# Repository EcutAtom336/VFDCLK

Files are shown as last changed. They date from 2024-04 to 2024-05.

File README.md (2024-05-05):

 # VFD 时钟 
 该项目是一个基于 ESP32 C3 微控制器的 VFD 时钟，可通过 Android 端软件进行配置
 ## 快速链接
 - [Github](https://github.com/EcutAtom336/VFDCLK/tree/master) 

 - [立创开源硬件平台](https://oshwhub.com/dter/vdf-clk)
 ## 特性
 - 使用 ESP32 C3 微控制器
 - 可通过 Android 端软件进行配置
 - 使用 VFD 显示屏，最高亮度 1000cd/m^2^
 - 内置一个蜂鸣器，可发出提示音
 - 内置光敏电阻，可实现自动亮度
 - 双 Type-C 设计，包含一个侧面 16Pin Type-C （下载和供电）和背面 6Pin Type-C （仅供电）
 - 右上螺丝可触摸设计，可进行简单交互

 ## 开始
 ### 所需工具
 - 镊子
 - 电烙铁
 - 热风枪 或 加热台
 - 万用表
 - 支持 USB 2.0 的 Type-C 数据线
 - 支持 BLE 的 Android 手机

 ### 调试建议
  1. 最后焊接 VFD 屏幕，以防加热损坏 VFD 屏幕。
  2. 烧录前先测试电源是否短路，以免损坏电脑 USB 接口。

 ### 烧录
 烧录时，请使用侧面 Type-C 接口。

 使用附件提供的 .bin 文件进行烧录，烧录方法如下。
 
 1. IDE 烧录
 [IDE 烧录方法](https://docs.espressif.com/projects/esp-techpedia/zh_CN/latest/esp-friends/get-started/try-firmware/try-firmware-platform.html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)
 2. Flash Download Tool 烧录
 [Flash Download Tool 烧录](https://docs.espressif.com/projects/esp-techpedia/zh_CN/latest/esp-friends/get-started/try-firmware/try-firmware-platform.html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)

 对于非开发人员，建议使用 Flash Download Tool 烧录。

 ## 使用方法
 1. 初次上电，长按右上螺丝 3s 进入配置模式，此时 VFD 时钟显示一次性设备码。
 2. 安装附件提供的 Android 软件进行配置。
 3. 当时间可能不准确时，时间分隔符会闪烁。

 ## 注意事项
 - 3D 外壳有两个，分为有脚垫和无脚垫（文件名分别为 shell_foot_pad.STL 和 shell_not_foor_pad.STL）。无脚垫的已验证。有脚垫的仅在无脚垫的基础上加上脚垫，未验证。
 - 面板打印选 1.5 mm 厚，只切割不打印。备注写“两款数量一样”。
 - 由于立创开源硬件平台审核机制，附件所提供的 apk 和 bin 可能不是最新，可前往 Github 查看是否有更新。
 - 为保证 ESP32 C3 天线校准成功以及系统稳定，请使用电压为 5V 且电流不低于 800mA 的电源进行供电。

 ## 安全提示
 - 尽管具有防回流设计，但也不要同时使用两个 Type-C 接口进行供电，以免发生意外。
 - 由于技术原因，配置时所输入的一次性设备码并不是蓝牙的配对码，因此时钟与 Android 手机并没有建立绑定关系，所以配置信息全部以明文发送。

 ## 未来可能更新的功能（画饼）
 - BLE OTA
 - 闹钟功能
 - 配置信息加密
 - 校园网认证

 ## 许可证
 本项目使用 GPL 3.0 许可证。

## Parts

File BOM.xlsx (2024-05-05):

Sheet: BOM
No. | Quantity | Designator | Footprint | Value | Device
1 | 1 | BUZZER1 | BUZ-SMD_L5.0-W5.5-P4.60 | 4kHz | MLT-5020
2 | 3 | C1,C7,C8 | C0603 | 10uF | CL10A106KP8NNNC
3 | 8 | C2,C3,C4,C9,C11,C14,C18,C22 | C0603 | 100nF | CAP_0603
4 | 3 | C5,C15,C17 | C0603 | 10nF | 0603B103K500NT
5 | 2 | C6,C19 | C0603 | 1uF | CAP_0603
6 | 4 | C10,C12,C13,C23 | C0805 | 22uF | CAP_0805
7 | 1 | C16 | C0603 | 22nF | CL10B223KB8NNNC
8 | 1 | C20 | C0603 | 22pF | CAP_0603
9 | 1 | C21 | C0603 | 20pF | CAP_0603
10 | 2 | D1,D4 | SOD-323_L1.8-W1.3-LS2.5-RD |  | 1N5819WS_C191023
11 | 2 | D2,D3 | SMA_L4.3-W2.6-LS5.0-RD |  | SS14_C2837270
12 | 1 | H1 | HDR-TH_4P-P2.54-V-M |  | HDR-M_2.54_1x4P
13 | 2 | L1,L2 | IND-SMD_L4.4-W4.2 | 6.8uH | FXL0420-6R8-M
14 | 1 | Q1 | SOT-23-3_L2.9-W1.3-P1.90-LS2.4-BR |  | SS8050_C2150
15 | 2 | R1,R2 | R0603 | 10R | Res_0603
16 | 1 | R3 | R0603 | 39K | Res_0603
17 | 4 | R4,R5,R6,R18 | R0603 | 10K | Res_0603
18 | 2 | R7,R8 | R0603 | 0.1R | Res_0603
19 | 4 | R9,R10,R11,R14 | R0603 | 5.1K | Res_0603
20 | 1 | R12 | R0603 | 37.4K | Res_0603
21 | 1 | R13 | R0603 | 1K | Res_0603
22 | 1 | R15 | R0603 | 100K | Res_0603
23 | 1 | R16 | R0603 | 43K | Res_0603
24 | 1 | R17 | RES-TH_L5.1-W4.3-P3.40-D0.5 |  | GL5516
25 | 2 | SW1,SW2 | SW-SMD_4P-L5.2-W5.2-P3.70-LS6.4 |  | TC-0522C-1.6-260G
26 | 1 | U1 | WIFIM-SMD_ESP32-C3-MINI-1 |  | ESP32-C3-MINI-1-H4_C2935306
27 | 1 | U2 | SOT-223-4_L6.5-W3.5-P2.30-LS7.0-BR |  | AMS1117-3.3_C347222
28 | 1 | U3 | TYPE-C-SMD_TYPE-C-31-D-05 |  | TYPE-C 6PLTH6.8-DJ
29 | 2 | U4,U6 | SOT-23-6_L2.9-W1.6-P0.95-LS2.8-BL |  | MT2492,MT3608
30 | 1 | U5 | SOT-23-6_L2.9-W1.6-P0.95-LS2.8-BR |  | TTP223E-BA6
31 | 1 | USB1 | USB-C-SMD_G-SWITCH_GT-USB-7010ASV |  | GT-USB-7010ASV
32 | 1 | VFD1 | 8-MD-06INKM |  | 8-MD-06INKM

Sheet: 装配螺丝
名称 | 型号 | 数量 | 备注
滚花手拧螺丝 | M2*5 | 8 | 暴露在外，建议不锈钢防止氧化
双通六角铜柱 | M2*7 | 4
单通六角铜柱 | M2*6+3 | 4

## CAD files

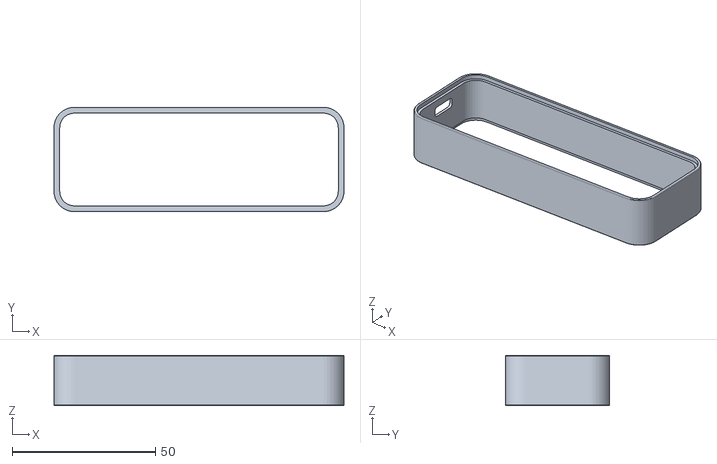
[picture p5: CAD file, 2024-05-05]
3D Model/shell_not_foor_pad.STL
101.4 x 36.4 x 17.6

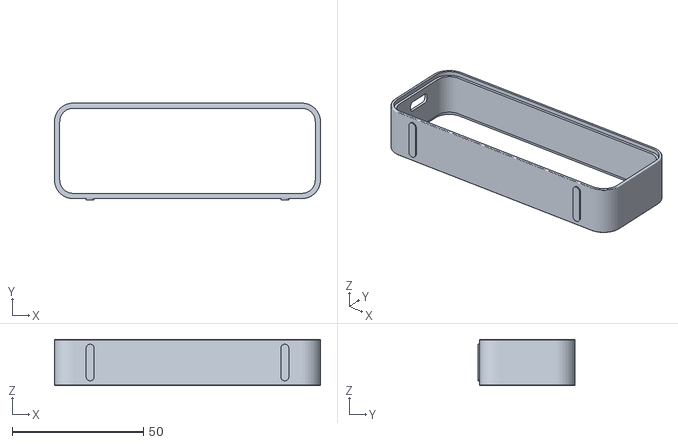
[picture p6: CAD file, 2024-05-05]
3D Model/shell_foot_pad.STL
101.4 x 36.9 x 17.6

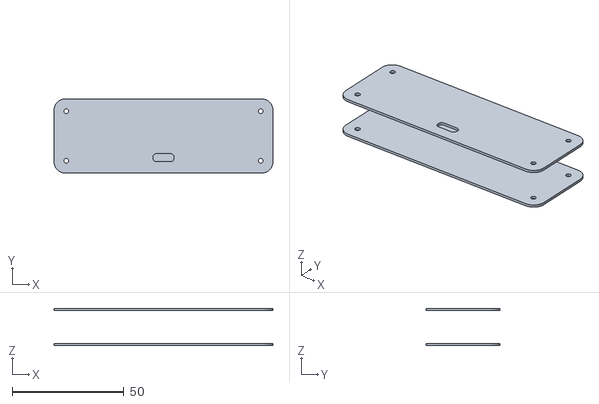
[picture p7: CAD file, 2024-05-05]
3D Model/panel.STL
98.2 x 33.2 x 16.6

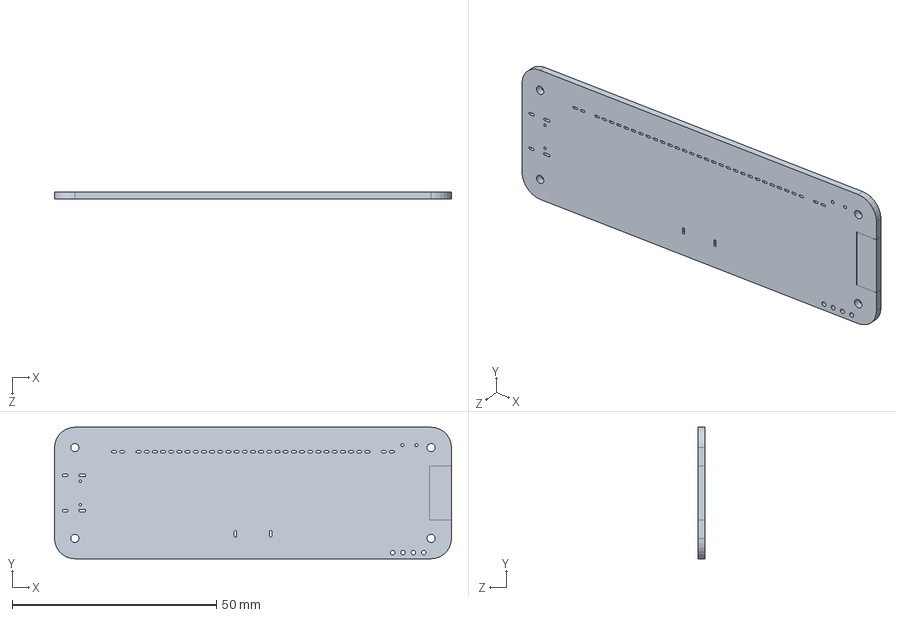
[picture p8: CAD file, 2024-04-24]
3D Model/Board.SLDPRT
97.2 x 32.2 x 1.60 mm

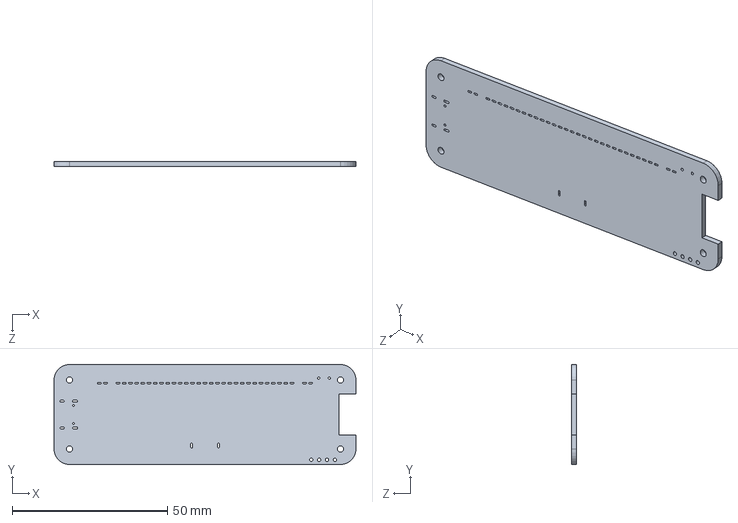
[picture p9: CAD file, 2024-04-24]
3D Model/零件20.SLDPRT
97.2 x 32.2 x 1.60 mm

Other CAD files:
3D Model/面板.SLDPRT

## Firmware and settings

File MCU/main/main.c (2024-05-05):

#include "VFD_8_MD_06INKM.h"
#include "life_cycle_manage.h"
#include "my_buzzer.c"
#include "my_sntp.h"
#include "my_spi.h"
#include "my_wifi.h"
//
#include "button_gpio.h"
#include "esp_event.h"
#include "esp_heap_caps.h"
#include "esp_log.h"
#include "esp_sntp.h"
#include "freertos/FreeRTOS.h"
#include "freertos/event_groups.h"
#include "freertos/task.h"
#include "iot_button.h"
#include "nvs_flash.h"

#define TAG "main"

void app_main(void) {
  esp_err_t esp_err;

  esp_err = nvs_flash_init();
  if (esp_err != ESP_OK) {
    ESP_LOGW(
        TAG,
        "initialize default nvs partition fail, reason: %s, erase default nvs "
        "partition",
        esp_err_to_name(esp_err));
    esp_err = nvs_flash_erase();
    if (esp_err != ESP_OK) {
      ESP_LOGE(TAG, "erase default nvs partition fail, reason: %s, reboot...",
               esp_err_to_name(esp_err));
      esp_restart();
      return;
    }
    ESP_LOGI(TAG, "erase default nvs partition success");
    esp_err = nvs_flash_init();
    if (esp_err != ESP_OK) {
      ESP_LOGE(
          TAG,
          "initialize default nvs partition fail again, reason: %s, reboot...",
          esp_err_to_name(esp_err));
      esp_restart();
      return;
    }
  }
  ESP_LOGI(TAG, "initialize default nvs partition success");

  esp_err = nvs_flash_init_partition("vfdclk");
  if (esp_err != ESP_OK) {
    ESP_LOGW(
        TAG,
        "initialize vfdclk nvs partition fail, reason: %s, erase vfdclk nvs "
        "partition",
        esp_err_to_name(esp_err));
    esp_err = nvs_flash_erase_partition("");
    if (esp_err != ESP_OK) {
      ESP_LOGE(TAG, "erase vfdclk nvs partition fail, reason: %s, reboot...",
               esp_err_to_name(esp_err));
      esp_restart();
      return;
    }
    ESP_LOGI(TAG, "erase vfdclk nvs partition success");
    esp_err = nvs_flash_init_partition("vfdclk");
    if (esp_err != ESP_OK) {
      ESP_LOGE(
          TAG,
          "initialize vfdclk nvs partition fail again, reason: %s, reboot...",
          esp_err_to_name(esp_err));
      esp_restart();
      return;
    }
  }
  ESP_LOGI(TAG, "vfdclk nvs partition init success");

  ESP_ERROR_CHECK(esp_event_loop_create_default());

  setenv("TZ", "CST-8", 1);
  tzset();
  my_sntp_init();
  my_spi_init();
  VFD_8_MD_06INKM_init();
  // VFD_8_MD_06INKM_aquire(portMAX_DELAY);
  // VFD_8_MD_06INKM_show_str("12:00:00", 0, 8);
  // return;
  my_buzzer_init();
  my_wifi_init();
  life_cycle_manage_init();
  life_cycle_manage_create(Atom336);

  // my_buzzer_tone(MY_BUZZER_TONE_NAME_START, 10);

  heap_caps_print_heap_info(MALLOC_CAP_DEFAULT);
}

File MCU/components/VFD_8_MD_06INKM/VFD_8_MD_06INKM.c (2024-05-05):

#include "VFD_8_MD_06INKM.h"
//
#include "VFD_type_defs.h"
//
#include "cJSON.h"
#include "driver/gpio.h"
#include "driver/spi_master.h"
#include "esp_adc/adc_cali.h"
#include "esp_adc/adc_oneshot.h"
#include "esp_log.h"
#include "esp_system.h"
#include "my_common.h"
#include "nvs_flash.h"
#include "soc/io_mux_reg.h"
//
#include <string.h>

#define TAG "VFD_8_MD_06INKM"

#define NVS_VFD_NS "vfd"
#define NVS_KEY_VFD_CONFIG "config"

#define JSON_KEY_VFD_MAIN "myVfd"
#define JSON_KEY_VFD_BRIGHTNESS "brightness"

// 亮度0-240
// #define VFD_8_MD_06INKM_DEFAULT_BRT 5

#define VFD_8_MD_06INKM_SPI SPI2_HOST
#define VFD_8_MD_06INKM_CS 1

#define VFD_8_MD_06INKM_GEN_CMD_W_DCRAM(DCRAM_address)                         \
  (uint8_t)((DCRAM_address & 0x1F) | 0x20)
#define VFD_8_MD_06INKM_GEN_CMD_W_CGRAM(CGRAM_address)                         \
  (uint8_t)((CGRAM_address & 0x07) | 0x40)
#define VFD_8_MD_06INKM_GEN_CMD_W_ADRAM(ADRAM_address)                         \
  (uint8_t)((ADRAM_address & 0x1F) | 0x60)
#define VFD_8_MD_06INKM_CMD_S_DISP_TIM (uint8_t)0xE0
#define VFD_8_MD_06INKM_DEFAULT_DISP_TIM (uint8_t)0x07
#define VFD_8_MD_06INKM_GEN_CMD_W_URAM(URAM_address)                           \
  (uint8_t)((URAM_address & 0x07) | 0x80)
#define VFD_8_MD_06INKM_CMD_S_DISP_BRT (uint8_t)0xE4
#define VFD_8_MD_06INKM_CMD_DISP_OFF (uint8_t)0xEA
#define VFD_8_MD_06INKM_CMD_DISP_ON (uint8_t)0xE8
#define VFD_8_MD_06INKM_CMD_STAND_BY (uint8_t)0xED
#define VFD_8_MD_06INKM_CMD_ACTIVE (uint8_t)0xEC

typedef struct {
  uint8_t brightness;
} VfdConfig_t;

spi_device_handle_t VFD_8_MD_06INKM_handle;
TaskHandle_t auto_brightness_task_handle;
SemaphoreHandle_t VFD_bus_mutex_handle;
SemaphoreHandle_t VFD_dev_mutex_handle;
TaskHandle_t VFD_dev_holder_task_handle;

// 由于数据量较小，使用中断传输的开销相对较大，所以使用轮询传输

// uint8_t VFD_8_MD_06INKM_custom_char_table[8][5] =
//     {{0, 0, 0, 0, 0},
//      {0, 0, 0, 0, 0},
//      {0, 0, 0, 0, 0},
//      {0, 0, 0, 0, 0},
//      {0, 0, 0, 0, 0},
//      {0, 0, 0, 0, 0},
//      {0, 0, 0, 0, 0},
//      {0, 0, 0, 0, 0}};

void VFD_get_config(VfdConfig_t *p_config) {
  const VfdConfig_t default_config = {
      .brightness = 0,
  };

  nvs_handle_t nvs_ro_handle;
  esp_err_t ret;
  ret = nvs_open_from_partition(NVS_VFDCLK_PARTITION_NAME, NVS_VFD_NS,
                                NVS_READONLY, &nvs_ro_handle);
  if (ret != ESP_OK) {
    ESP_LOGW(TAG, "get config open nvs fail, use default config, reason: %s",
             esp_err_to_name(ret));
    memcpy(p_config, &default_config, sizeof(VfdConfig_t));
    return;
  }

  size_t my_vfd_config_size = sizeof(VfdConfig_t);
  ret = nvs_get_blob(nvs_ro_handle, NVS_KEY_VFD_CONFIG, p_config,
                     &my_vfd_config_size);
  if (ret != ESP_OK) {
    ESP_LOGW(TAG, "get config read fail, use default config,reason: %s",
             esp_err_to_name(ret));
    nvs_close(nvs_ro_handle);
    memcpy(p_config, &default_config, sizeof(VfdConfig_t));
    return;
  }

  nvs_close(nvs_ro_handle);
}

void VFD_save_config(const VfdConfig_t *p_config) {
  nvs_handle_t nvs_rw_handle;
  esp_err_t esp_ret;
  esp_ret = nvs_open_from_partition(NVS_VFDCLK_PARTITION_NAME, NVS_VFD_NS,
                                    NVS_READWRITE, &nvs_rw_handle);
  if (esp_ret != ESP_OK) {
    ESP_LOGE(TAG, "save config open nvs fail, reason: %s, reboot...",
             esp_err_to_name(esp_ret));
    esp_restart();
  }

  esp_ret = nvs_set_blob(nvs_rw_handle, NVS_KEY_VFD_CONFIG, p_config,
                         sizeof(VfdConfig_t));
  if (esp_ret != ESP_OK) {
    ESP_LOGE(TAG, "save config set fail, reason: %s, reboot...",
             esp_err_to_name(esp_ret));
    esp_restart();
  }

  esp_ret = nvs_commit(nvs_rw_handle);
  if (esp_ret != ESP_OK) {
    ESP_LOGE(TAG, "nvs commit fail, reason: %s, reboot...",
             esp_err_to_name(esp_ret));
    esp_restart();
  }

  nvs_close(nvs_rw_handle);

  ESP_LOGI(TAG, "save config success");
}

void VFD_get_config_json(cJSON *config_json_parent) {
  VfdConfig_t config;
  VFD_get_config(&config);

  cJSON *VFD_config_json = cJSON_CreateObject();
  cJSON_AddNumberToObject(VFD_config_json, JSON_KEY_VFD_BRIGHTNESS,
                          config.brightness);

  cJSON_AddItemToObject(config_json_parent, JSON_KEY_VFD_MAIN, VFD_config_json);
}

void VFD_analysis_config_json(cJSON *config_json_parent) {
  VfdConfig_t config;
  VFD_get_config(&config);

  cJSON *VFD_config_json =
      cJSON_GetObjectItem(config_json_parent, JSON_KEY_VFD_MAIN);
  if (VFD_config_json == NULL) {
    ESP_LOGI(TAG, STRING_CONFIG_JSON_NOT_FOUND);
    return;
  }

  cJSON *brightness_json =
      cJSON_GetObjectItem(VFD_config_json, JSON_KEY_VFD_BRIGHTNESS);
  if (brightness_json != NULL) {
    config.brightness = (uint8_t)cJSON_GetNumberValue(brightness_json);
  }

  VFD_save_config(&config);
}

void VFD_8_MD_06INKM_write(uint8_t *p_data, uint8_t len) {
  spi_transaction_t spi_transaction = {
      .flags = SPI_TRANS_MODE_OCT,
      .length = len * 8,
      .rxlength = 0,
      .user = NULL,
  };
  if (len <= 4) {
    spi_transaction.flags |= SPI_TRANS_USE_TXDATA;
    for (size_t i = 0; i < len; i++) {
      spi_transaction.tx_data[i] = *p_data;
      p_data++;
    }
  } else if (len > 4) {
    spi_transaction.tx_buffer = p_data;
  }
  // xSemaphoreTake(VFD_bus_mutex_handle, portMAX_DELAY);
  ESP_ERROR_CHECK(
      spi_device_polling_transmit(VFD_8_MD_06INKM_handle, &spi_transaction));
  // xSemaphoreGive(VFD_bus_mutex_handle);
}

VfdErr_t VFD_is_hoder() {
  if (VFD_dev_holder_task_handle == NULL) {
    ESP_LOGW(TAG, "check vfd dev holder: on holder");
    return kVfdFail;
  }
  if (VFD_dev_holder_task_handle != xTaskGetCurrentTaskHandle()) {
    ESP_LOGW(TAG, "check vfd dev holder: not holder");
    return kVfdFail;
  }
  return kVfdSuccess;
}

void VFD_8_MD_06INKM_show_str(char *s, uint8_t start_pos_base_0,
                              uint8_t str_len) {
  if (VFD_is_hoder() != kVfdSuccess) {
    ESP_LOGW(TAG, "show string fail");
    return;
  }
  if (start_pos_base_0 > 7)
    return;
  uint8_t data[9] = {
      VFD_8_MD_06INKM_GEN_CMD_W_DCRAM(start_pos_base_0),
  };
  if (str_len + start_pos_base_0 > 8)
    str_len = 8 - start_pos_base_0;
  for (size_t i = 0; i < str_len; i++)
    data[i + 1] = s[i] >= 32 && s[i] <= 126 ? s[i] : ' ';
  VFD_8_MD_06INKM_write(data, str_len + 1);
}

// void VFD_8_MD_06INKM_modify_custom_char(uint8_t *custom_char, uint8_t
// target_pos)
// {
//     if (target_pos > 7)
//         return;
//     // for (size_t i = 0; i < 5; i++)
//     // {
//     //     VFD_8_MD_06INKM_custom_char_table[target_pos][i] = *custom_char++;
//     // }
//     // VFD_8_MD_06INKM_write_CGRAM(target_pos, custom_char, 5);
//     VFD_8_MD_06INKM_write(VFD_8_MD_06INKM_GEN_CMD_W_CGRAM(target_pos),
//     custom_char, 5);
// }

void VFD_8_MD_06INKM_init_display_timing() {
  uint8_t data[] = {VFD_8_MD_06INKM_CMD_S_DISP_TIM,
                    VFD_8_MD_06INKM_DEFAULT_DISP_TIM};
  VFD_8_MD_06INKM_write(data, 2);
}
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

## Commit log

2024-04-24 首次提交
    [Board.SLDPRT, partitions.csv, 零件20.SLDPRT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]
2024-04-25 删除无用注释 修改 readme.md 路径
2024-04-25 修改分区
    [partitions.csv]
2024-04-25 上传 apk
2024-04-25 更新 readme.md
2024-04-25 上传 BOM
    [BOM.xlsx]
2024-04-25 修改 licence.md 路径
2024-05-05 上传实物图和相关文件
2024-05-05 上传 BOM 表
    [BOM.xlsx]
2024-05-05 更新 Android 端软件
2024-05-05 更新 3d 模型
    [外壳_无脚垫.STL, 外壳_有脚垫.STL, 面板.SLDPRT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]
2024-05-05 更新 VFD 时钟软件 1. 添加开机动画 2. 优化架构
2024-05-05 3d 文件名更改为英文
    [panel.STL, shell_foot_pad.STL, shell_not_foor_pad.STL]
